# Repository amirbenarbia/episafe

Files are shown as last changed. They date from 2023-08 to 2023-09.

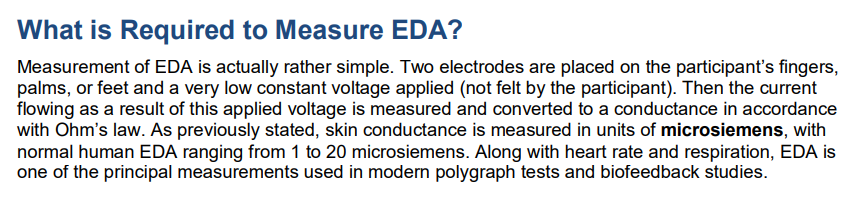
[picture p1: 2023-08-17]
SOLO/EDA/Researches/principeEDA.png

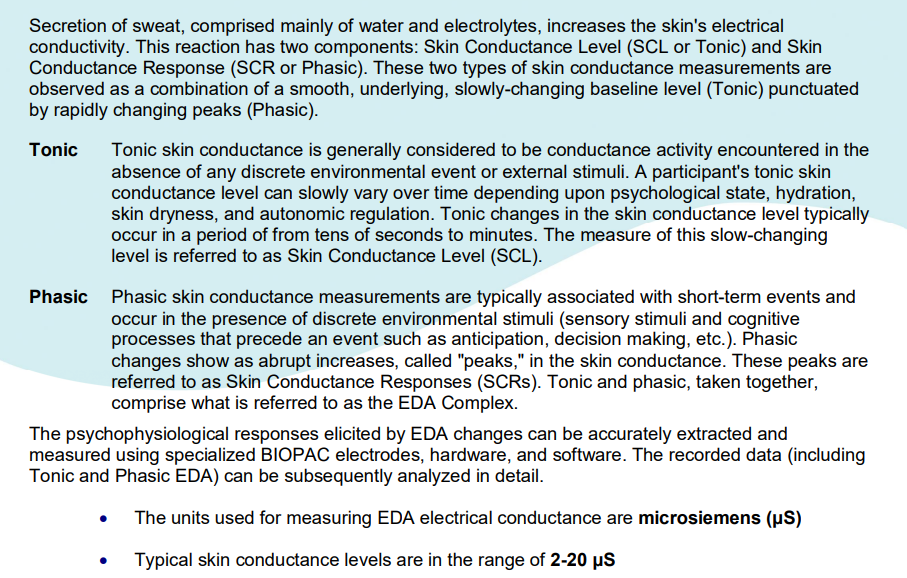
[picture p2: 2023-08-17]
SOLO/EDA/Researches/SCLvsSCR.png

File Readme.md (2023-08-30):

# Episafe Sensor Monitoring System

## Overview

The Episafe Sensor Monitoring System is an embedded IoT system aimed at providing real-time sensor data collection and Bluetooth-based transmission to a host device. Built on the ESP32 microcontroller, the system captures various physiological data points including heart rate, body temperature, acceleration, conductance, and more. With a built-in battery monitoring system, it offers a highly portable and efficient platform for health and safety applications.

## Table of Contents

- [Overview](#overview)
- [Prerequisites](#prerequisites)
- [Installation](#installation)
- [Hardware Setup](#hardware-setup)
- [Usage](#usage)
- [Data Points](#data-points)
- [Error Handling](#error-handling)
- [Contributing](#contributing)
- [License](#license)

## Prerequisites

- ESP32 Development Board
- Arduino IDE (version >= 1.8.10)
- Pulse Sensor
- Adafruit MPU6050 Accelerometer and Gyroscope
- Adafruit MLX90614 Temperature Sensor
- Additional components (LEDs, buttons, etc.)

## Installation

1. **Clone the repository**

   ```
   git clone https://github.com/yourusername/Episafe.git
   ```

2. **Open Arduino IDE**

3. **Install Required Libraries**

   Navigate to `Sketch > Include Library > Manage Libraries...`, then search and install the following libraries:
   - OneButton
   - Adafruit_MLX90614
   - Adafruit_MPU6050
   - BluetoothSerial
   - ArduinoJson

4. **Select Board and Port**

   Choose `ESP32` from `Tools > Board` and select the COM Port the board is connected to.

5. **Compile and Upload**

   Compile the code by clicking the checkmark button, and then upload it to your ESP32 by clicking the right-arrow button.

## Hardware Setup

Follow the hardware schematic [here](link_to_schematic) to connect all the components.

## Usage

The system starts in the "Data Capture" state, where it begins to read the sensor data. The data is stored in an internal buffer until it reaches the specified limit, at which point it moves to the "Data Transmission" state.

### Buttons

- **Button 1**: 
  - Single Click: Manually trigger sensor reading
  - Long Press: Trigger "Crisis" state

- **Button 2**: 
  - Double Click: Report false alarm
  - Long Press: Reset the system

## Data Points

- Heart Rate (BPM)
- Body Temperature (°C)
- Acceleration (m/s^2)
- Conductance (µS)
- Battery Level (%)

## Error Handling

The system has built-in error handling mechanisms to deal with common issues such as Bluetooth disconnection, sensor failures, and more. Errors are indicated by specific LED patterns.

## Contributing

If you wish to contribute, please fork the repository and submit a pull request. For major changes, please open an issue to discuss the proposed changes.

## License

Feel free to clone, modify, and use the code as per your requirements. If you find any issues or have feature requests, please open an issue or submit a pull request.

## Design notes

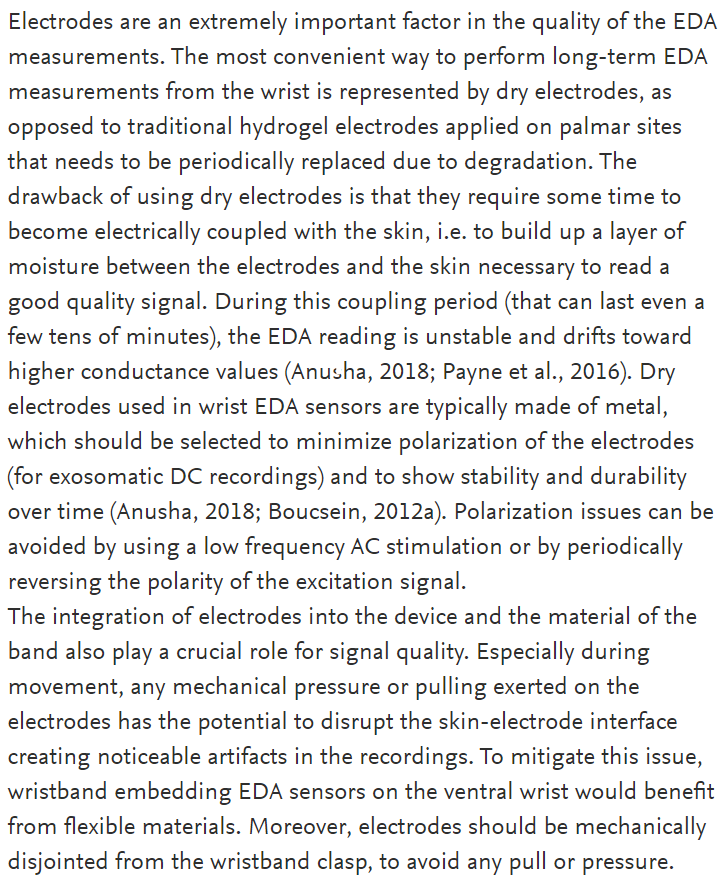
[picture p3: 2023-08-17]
SOLO/EDA/Researches/electrode impact to EDA .png

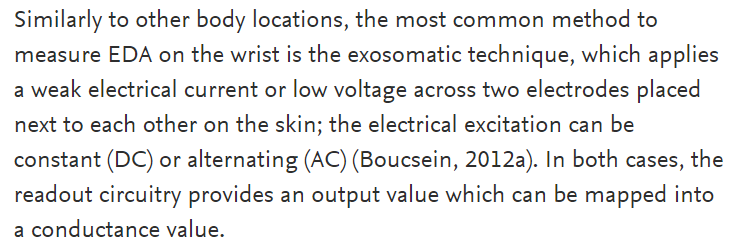
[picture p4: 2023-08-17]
SOLO/EDA/Researches/Wrist method measurments .png

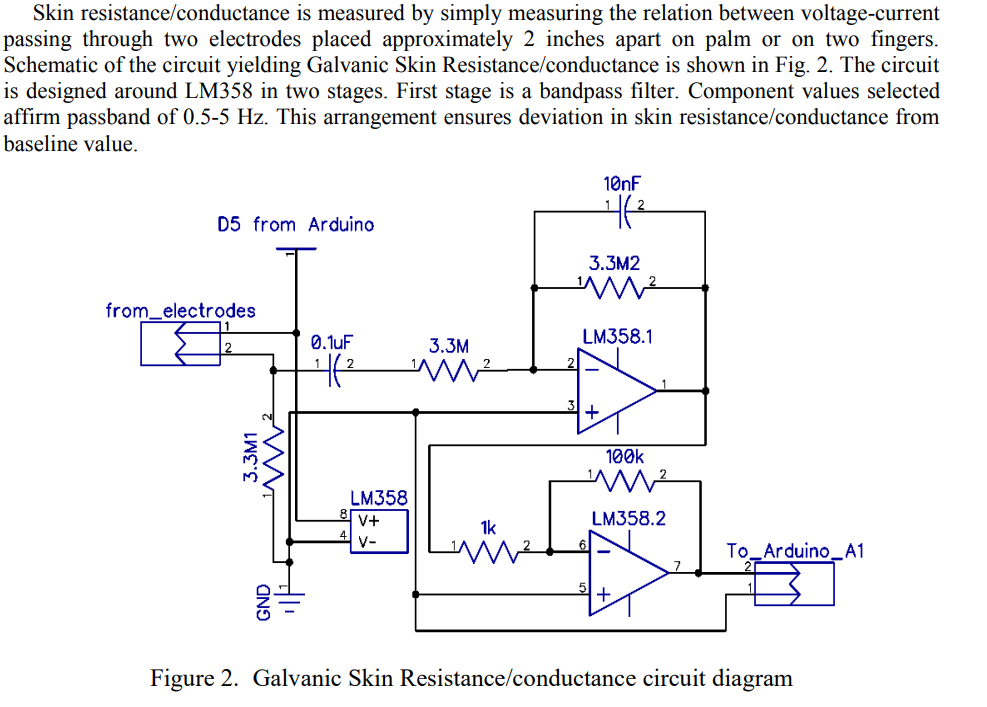
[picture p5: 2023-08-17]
SOLO/EDA/Researches/EDAcircuits2.0.png

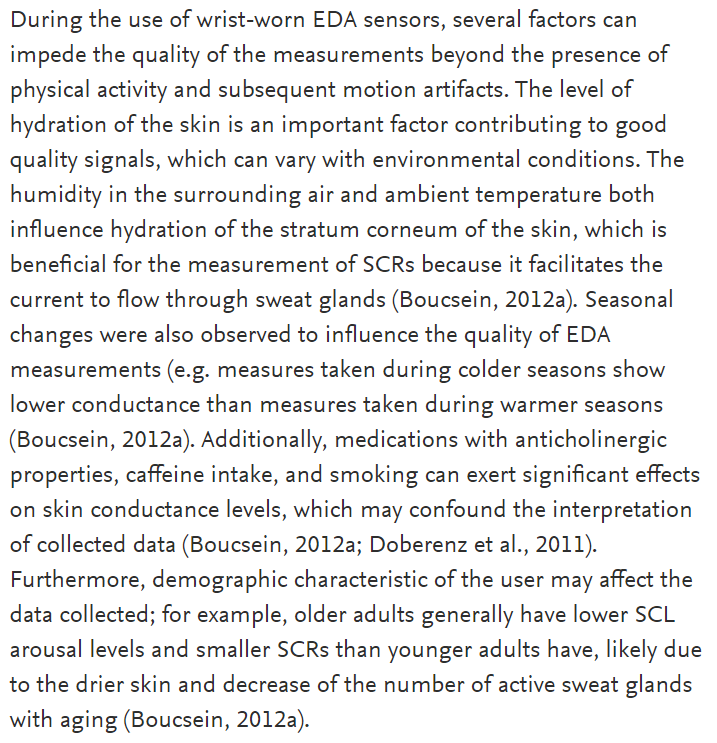
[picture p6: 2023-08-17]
SOLO/EDA/Researches/factors .png

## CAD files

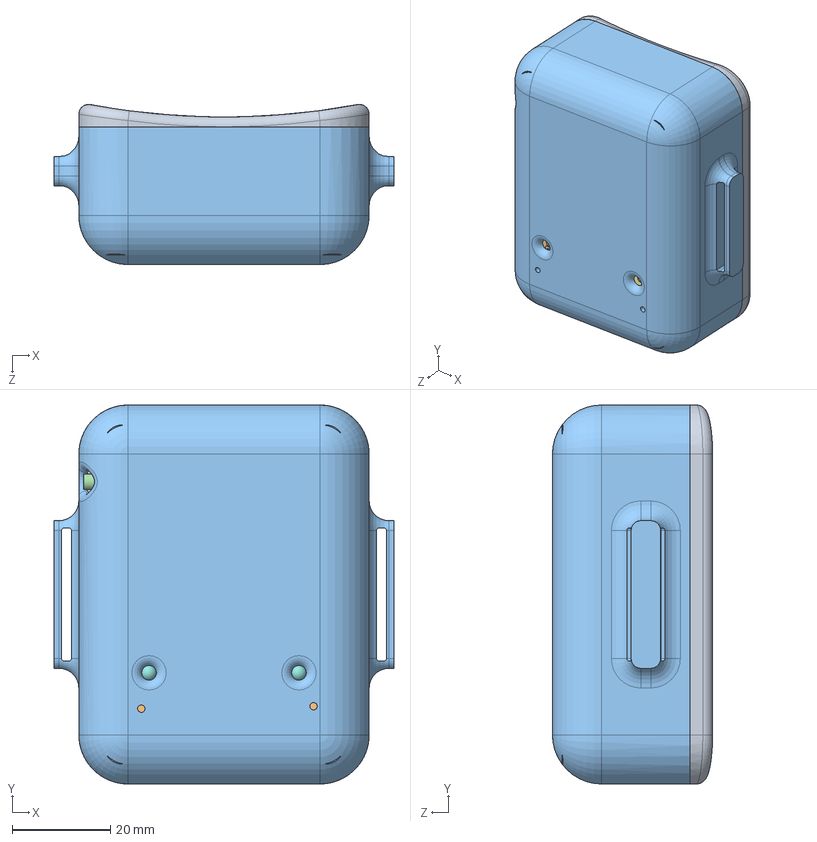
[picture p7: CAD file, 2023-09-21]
EpiSafe_Solidworks/Episafe-assembly-v2.SLDASM
69.0 x 77.0 x 32.6 mm
Episafev1v2(p1)
bt
Episafev2(p2)
SOLID.step x 6
SOLID-0.step x 11
SOLID-1.step x 2
COMPOUND.step
SOLID-2.step x 2
SOLID-3.step
SOLID-4.step x 2
SOLID-5.step
SOLID-6.step
SOLID-7.step
COMPOUND-8.step
COMPOUND-9.step
COMPOUND-10.step
COMPOUND-11.step
Episafe PCB.step

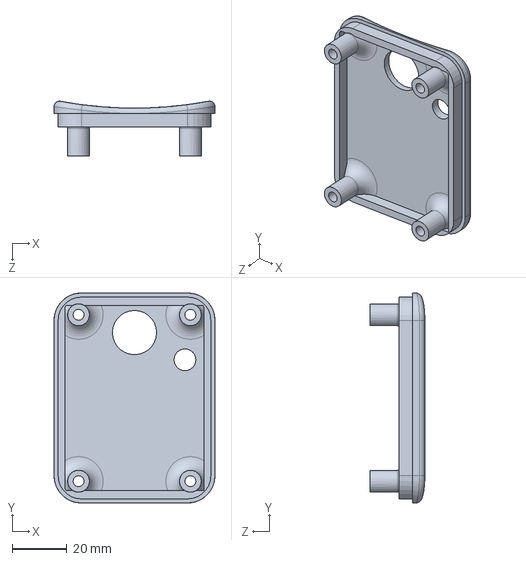
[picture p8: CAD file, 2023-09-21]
EpiSafe_Solidworks/Episafev1v2(p1).SLDPRT
59.0 x 77.0 x 20.1 mm

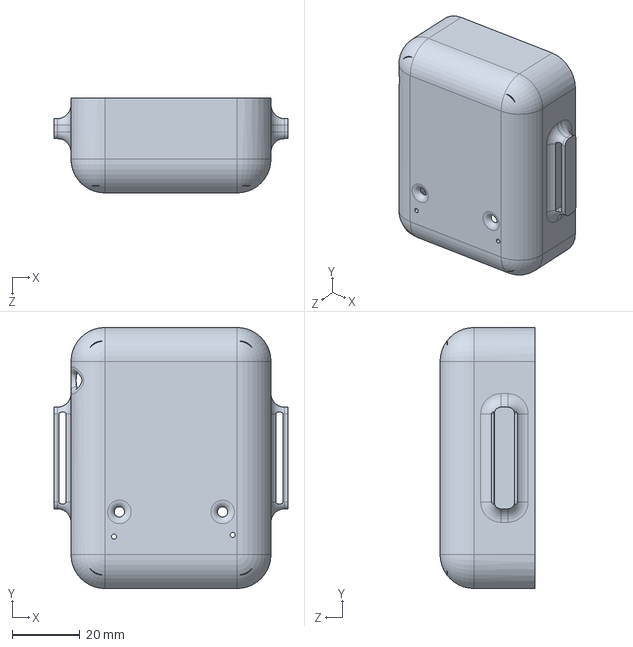
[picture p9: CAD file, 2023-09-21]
EpiSafe_Solidworks/Episafev2(p2).SLDPRT
69.0 x 77.0 x 28.0 mm

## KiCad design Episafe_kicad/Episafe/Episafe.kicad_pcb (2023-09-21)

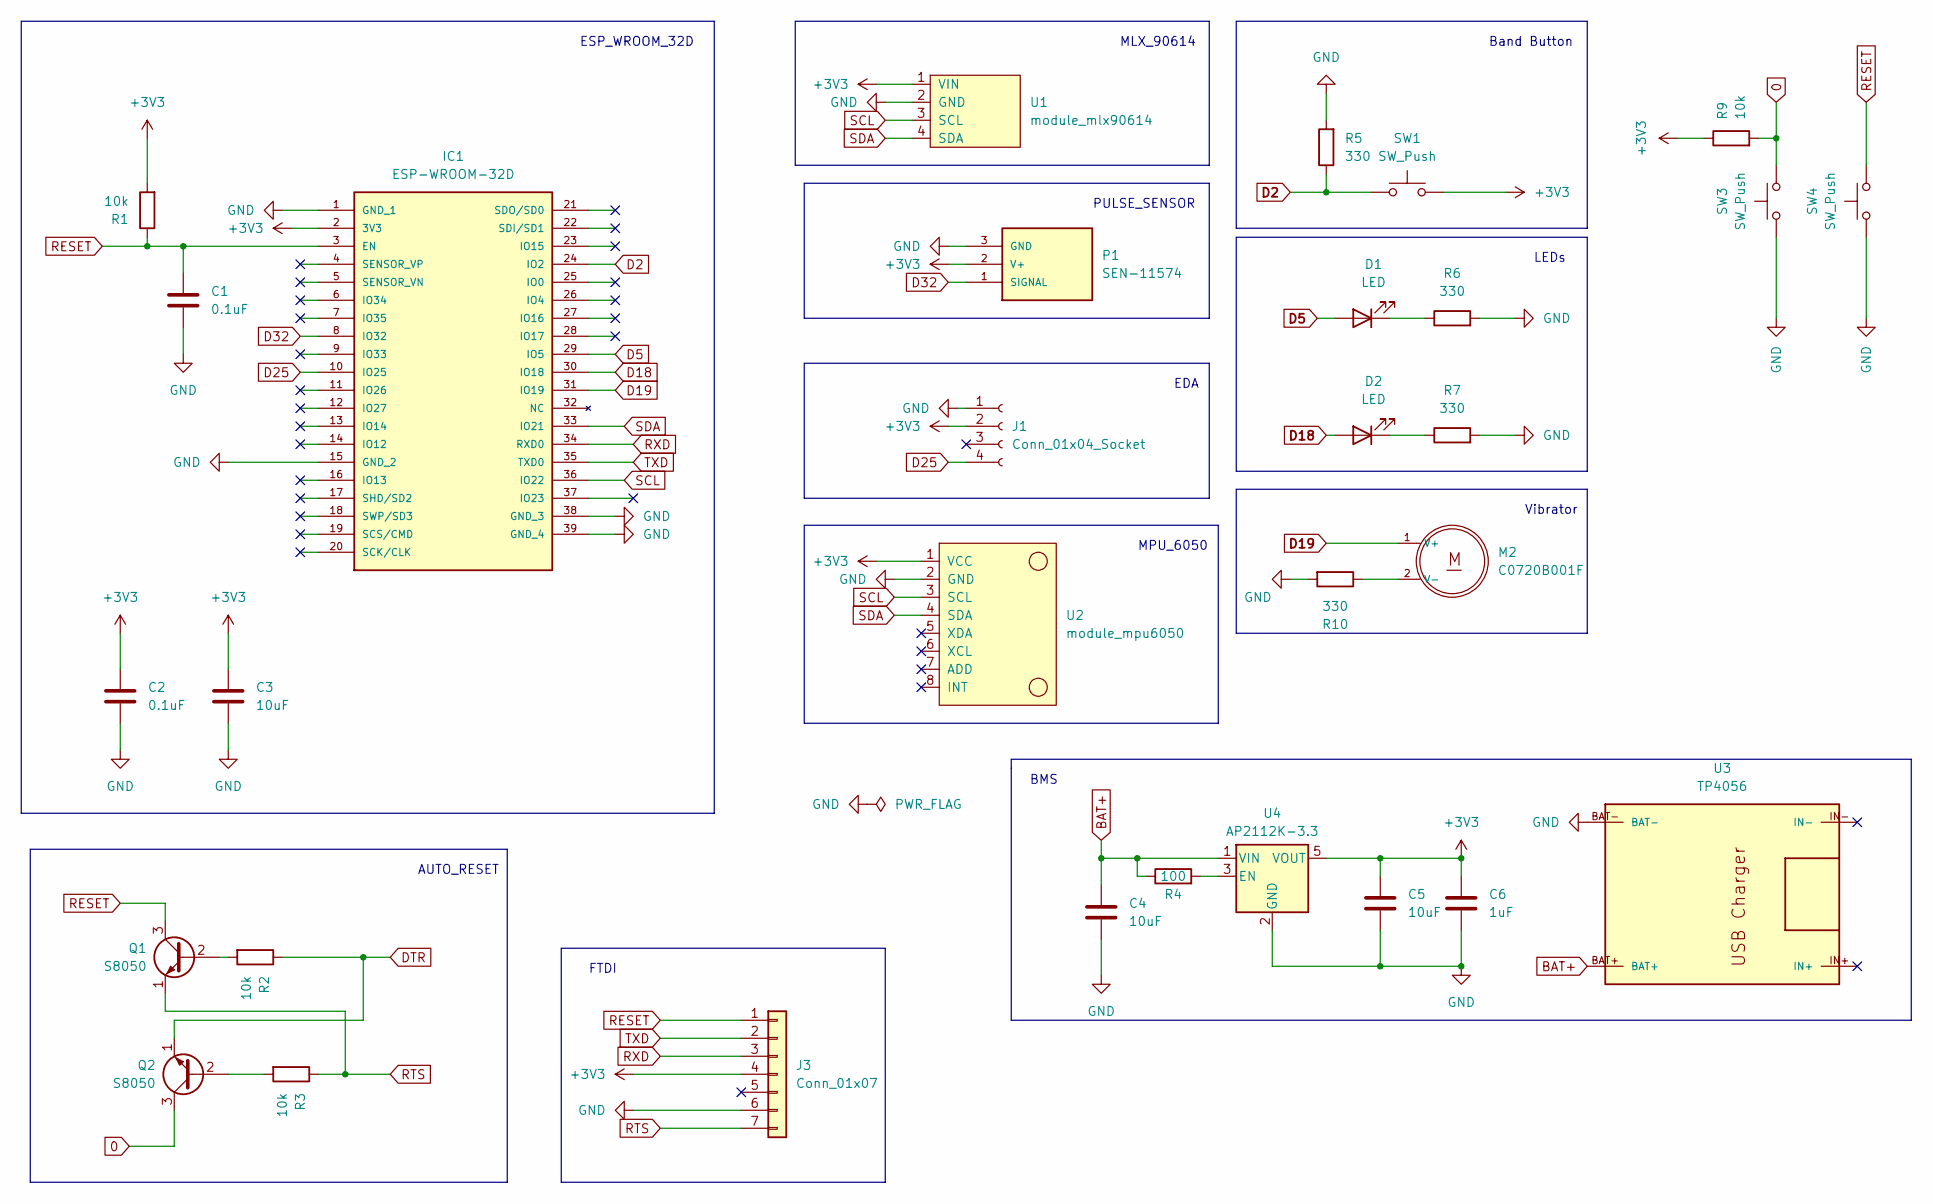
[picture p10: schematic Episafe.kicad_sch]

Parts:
C1, C2: 0.1uF; C_1206_3216Metric_Pad1.33x1.80mm_HandSolder
C3, C4, C5: 10uF; C_1206_3216Metric_Pad1.33x1.80mm_HandSolder
C6: 1uF; C_1206_3216Metric_Pad1.33x1.80mm_HandSolder
D1, D2: LED; LED_D3.0mm
IC1: ESP-WROOM-32D; ESPWROOM32D; MOUSER_PART_NUMBER 356-ESP-WROOM-32D
J1: Conn_01x04_Socket; PinSocket_1x04_P2.54mm_Vertical
J3: Conn_01x07; PinSocket_1x07_P2.54mm_Vertical
M2: C0720B001F; XDCR_C0720B001F
P1: SEN-11574; XDCR_SEN-11574
Q1, Q2: S8050; TO-92_Inline
R1, R2, R3, R9: 10k; R_1206_3216Metric_Pad1.30x1.75mm_HandSolder
R4: 100; R_1206_3216Metric_Pad1.30x1.75mm_HandSolder
R5, R6, R7, R10: 330; R_1206_3216Metric_Pad1.30x1.75mm_HandSolder
SW1, SW3, SW4: SW_Push; SW_DIP_SPSTx01_Slide_6.7x4.1mm_W6.73mm_P2.54mm_LowProfile_J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
U1: module_mlx90614
U2: module_mpu6050
U3: TP4056
U4: AP2112K-3.3; SOT-23-5

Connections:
0: Q2.3 (C), R9.2, SW3.2
+3V3: C2.1, C3.1, C5.1, C6.1, IC1.2 (3V3), J1.2, J3.4, P1.2 (V+), R1.2, R9.1, SW1.2, U1.1 (VIN), U2.1 (VCC), U4.5 (VOUT)
BAT+: C4.1, R4.1, U3.BAT+, U4.1 (VIN)
D2: IC1.24 (IO2), R5.1, SW1.1
D5: D1.2 (A), IC1.29 (IO5)
D18: D2.2 (A), IC1.30 (IO18)
D19: IC1.31 (IO19), M2.1 (V+)
D25: IC1.10 (IO25), J1.4
D32: IC1.8 (IO32), P1.1 (SIGNAL)
DTR: Q2.1 (E), R2.1
GND: C1.2, C2.2, C3.2, C4.2, C5.2, C6.2, IC1.1 (GND_1), IC1.15 (GND_2), IC1.38 (GND_3), IC1.39 (GND_4), J1.1, J3.6, P1.3 (GND), R5.2, R6.2, R7.2, R10.2, SW3.1, SW4.1, U1.2 (GND), U2.2 (GND), U3.BAT-, U4.2 (GND)
unnamed: D1.1 (K), R6.1
unnamed: D2.1 (K), R7.1
unnamed: M2.2 (V-), R10.1
unnamed: Q1.2 (B), R2.2
unnamed: Q2.2 (B), R3.2
unnamed: R4.2, U4.3 (EN)
RESET: C1.1, IC1.3 (EN), J3.1, Q1.3 (C), R1.1, SW4.2
RTS: J3.7, Q1.1 (E), R3.1
RXD: IC1.34 (RXD0), J3.3
SCL: IC1.36 (IO22), U1.3 (SCL), U2.3 (SCL)
SDA: IC1.33 (IO21), U1.4 (SDA), U2.4 (SDA)
TXD: IC1.35 (TXD0), J3.2

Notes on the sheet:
EDA
PULSE_SENSOR
MLX_90614
FTDI
MPU_6050
Vibrator
AUTO_RESET
ESP_WROOM_32D
BMS
LEDs
Band Button

Board: 2 copper layers, 31 parts (1 on the bottom side), 23 nets, no tracks yet.

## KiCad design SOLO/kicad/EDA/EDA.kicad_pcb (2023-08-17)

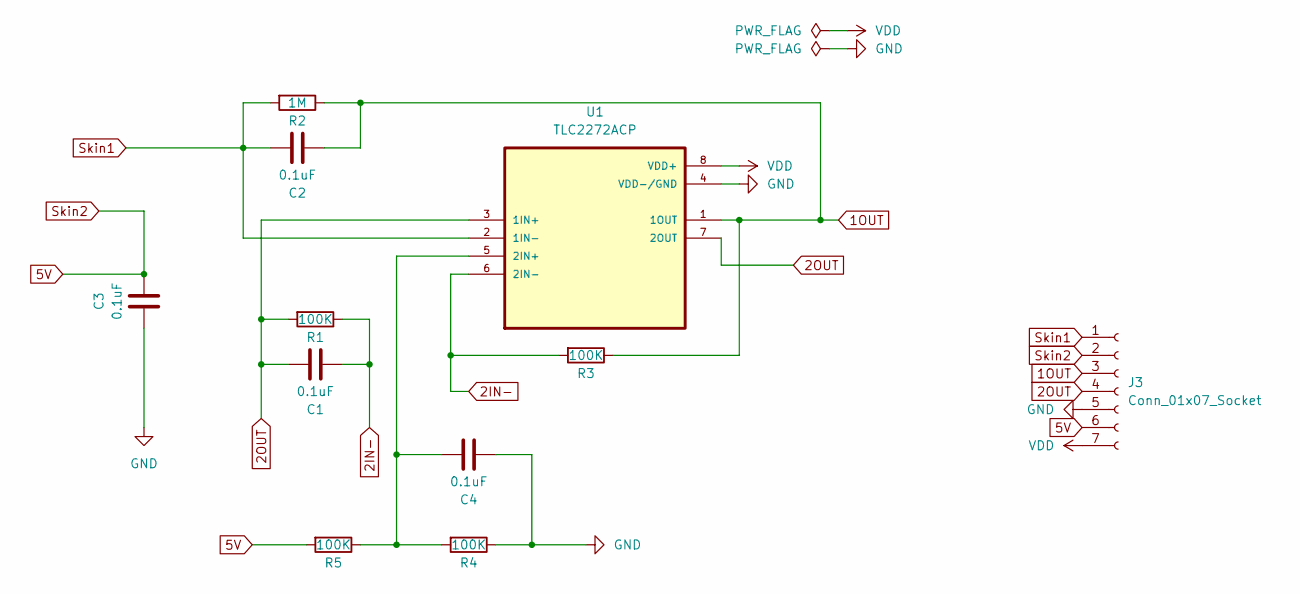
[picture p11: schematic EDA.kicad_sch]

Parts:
C1, C2, C3, C4: 0.1uF; C_Disc_D3.0mm_W1.6mm_P2.50mm
J3: Conn_01x07_Socket; JST_XH_B7B-XH-A_1x07_P2.50mm_Vertical
R1, R3, R4, R5: 100K; R_Axial_DIN0207_L6.3mm_D2.5mm_P10.16mm_Horizontal
R2: 1M; R_Axial_DIN0207_L6.3mm_D2.5mm_P10.16mm_Horizontal
U1: TLC2272ACP; DIP794W45P254L959H508Q8

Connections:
1OUT: C2.1, J3.3, R2.1, R3.1, U1.1 (1OUT)
2IN-: C1.1, R1.1, R3.2, U1.6 (2IN-)
2OUT: C1.2, J3.4, R1.2, U1.3 (1IN+), U1.7 (2OUT)
5V: C3.2, J3.2, J3.6, R5.2; also elsewhere on the board
GND: C3.1, C4.1, J3.5, R4.1, U1.4 (VDD-/GND)
unnamed: C4.2, R4.2, R5.1, U1.5 (2IN+)
Skin1: C2.2, J3.1, R2.2, U1.2 (1IN-)
VDD: J3.7, U1.8 (VDD+)

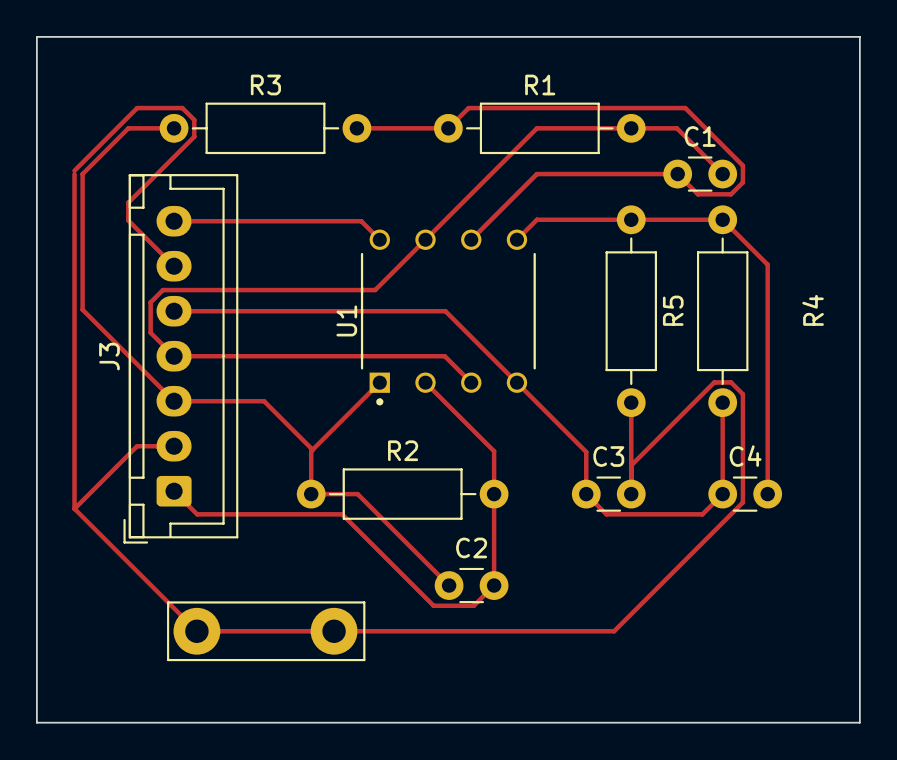
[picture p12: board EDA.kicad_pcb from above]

Board: 2 copper layers, 45.7 x 38.1 mm, 12 parts (0 on the bottom side), 8 nets.

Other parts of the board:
JP1: Jumper_2_Open; TestPoint_Bridge_Pitch7.62mm_Drill1.3mm

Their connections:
5V: JP1.1 (A); also elsewhere on the board

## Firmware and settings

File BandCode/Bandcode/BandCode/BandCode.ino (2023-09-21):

#include <OneButton.h>
#include <Wire.h>
#include <Adafruit_MLX90614.h>
#include <BluetoothSerial.h>
#include <Adafruit_MPU6050.h>
#include <Adafruit_Sensor.h>
#include <ArduinoJson.h>

extern "C" {
#include "esp_bt_device.h"
}

#define vib 19
#define pb1 2
//#define pb2 4
#define PulseSensorPurplePin 32
#define EDA_pin 25
#define LED_ERROR_PIN 5
#define LED_Sent 5
#define LED_collect 18
#define EDA_TH_PER_EPOCH 5
#define MAX_READ 1024
#define Threshold 2000
#define DURATION_COLLECT 250
#define DURATION_SENDING 1500
#define RECORDING_DURATION 20 * 1000
#define DATA_INTERVAL 250
#define MAX_DATA_POINTS RECORDING_DURATION / DATA_INTERVAL

int enableDebugOutput = 0;
TaskHandle_t BluetoothTaskHandle = NULL;
TaskHandle_t ButtonTaskHandle = NULL;

OneButton b1 = OneButton(
  pb1,    // Input pin for the button
  false,  // Button is active high
  false   // Disable internal pull-up resistor
);
/*OneButton b2 = OneButton(
  pb2,    // Input pin for the button
  false,  // Button is active high
  false   // Disable internal pull-up resistor
);*/
enum ErrorType { BT_DISCONNECTED,
                 BT_DISCONNECTED_WHILE_SENDING,
                 SENSOR_INIT_FAIL,
                 EDA_NEG };
struct SensorData {
  int pulseSensorValue;
  float objectTempC;
  float conductance;
  float accelerationX;
  float accelerationY;
  float accelerationZ;
  float temperature;
  float timeStamp;
  float batteryLevel;
};



void showError(ErrorType error);
float read_eda(int pin);
String Query(SensorData dt);
void readSensors(SensorData& data);
void sensorTask(void* parameter);
void bluetoothTask(void* parameter);
void blinkLED(int ledPin, int blinkDuration, int);
float readBatteryLevel(int pin);
float roundToOneDecimal(float num);
void  readHeartRateSensor(SensorData& data); 
void readTemperatureSensor(SensorData& data); 
void readAccelerometer(SensorData& data); 
void readEDA(SensorData& data); 
  
BluetoothSerial SerialBT;
Adafruit_MPU6050 mpu;
Adafruit_MLX90614 mlx = Adafruit_MLX90614();
int Signal, beatsPerMinute;
unsigned long lastBeatTime = 0, currentBeatTime, startTime;
int dataCount = 0;

SensorData dataBuffer[MAX_DATA_POINTS];

QueueHandle_t dataQueue;
String dataString = "";
int BATTERY_PIN = 3;
uint8_t mac[6];

void setup() {
  Serial.begin(115200);
  pinMode(EDA_pin, INPUT);
  pinMode(vib, OUTPUT);
  setupButtons(); //push buttons
  mlx.begin();
  mpu.begin();
  SerialBT.begin("Episafe");
  dataQueue = xQueueCreate(5, sizeof(SensorData));
  esp_read_mac(mac, ESP_MAC_BT);
  xTaskCreatePinnedToCore(sensorTask, "SensorTask", 30000, NULL, 1, NULL, 0);
  xTaskCreatePinnedToCore(buttonTask,"ButtonTask",30000,NULL,2,&ButtonTaskHandle,1);
}
void loop() {
  b1.tick();
  vTaskDelay(pdMS_TO_TICKS(500));
}

void showError(ErrorType error) {
  switch (error) {
    case BT_DISCONNECTED:
        Serial.println("Bluetooth Disconnected!");
      blinkLED(LED_ERROR_PIN, 300, 3);
      break;
    case SENSOR_INIT_FAIL:
        Serial.println("Sensor Initialization Failed!");
      blinkLED(LED_ERROR_PIN, 300, 3);
      break;
    case EDA_NEG:
        Serial.println("EDA-conductance negative");
      blinkLED(LED_ERROR_PIN, 150, 2);
      break;
    case BT_DISCONNECTED_WHILE_SENDING:
        Serial.println("FAILED TO SEND..");
      blinkLED(LED_ERROR_PIN, 150, 4);
      break;
  }
}
float read_eda(int pin) {
  int sensorValue = 0;
  int gsr_average = 0;
  int human_resistance = 0;
  int EDA_th_per_epch = 5;

  long sum = 0;
  for (int i = 0; i < EDA_th_per_epch; i++) {
    sensorValue = analogRead(pin);
    sum += sensorValue;
  }
  gsr_average = sum / EDA_th_per_epch;
  human_resistance = ((4096 + 2 * gsr_average) * 10000) / (2048 - gsr_average);

  return ((1.0 / human_resistance) * 1000000);
}
String Query(SensorData dt) {
  String result;

  result += "EPISAFE/";
  result += String(mac[0], HEX) + ":" + String(mac[1], HEX) + ":" + String(mac[2], HEX) +String(mac[3], HEX) + ":" + String(mac[4], HEX) + ":" + String(mac[5], HEX) + ",";
  result += String(roundToOneDecimal(dt.timeStamp)) + ",";
  result += String(roundToOneDecimal(dt.pulseSensorValue)) + ",";
  result += String(roundToOneDecimal(dt.objectTempC)) + ",";
  result += String(roundToOneDecimal(dt.accelerationX)) + ",";
  result += String(roundToOneDecimal(dt.accelerationY)) + ",";
  result += String(roundToOneDecimal(dt.accelerationZ)) + ",";
  result += String(roundToOneDecimal(dt.temperature)) + ",";
  result += String(roundToOneDecimal(dt.conductance)) + ",";
  result += String(roundToOneDecimal(dt.batteryLevel));

  result += "#";

  return result;
}

void readSensors(SensorData& data) {
  //HR
  readHeartRateSensor(data); 

  //TMPC
  readTemperatureSensor(data); 

  //ACC
  readAccelerometer(data); 

  //EDA
  readEDA(data); 

  //battery
  read_batt_lvl(data);   

  //---------
  if (dataCount < MAX_DATA_POINTS) {
    dataBuffer[dataCount] = data;
    dataCount++;
  }
  data.timeStamp = (float)(millis() - startTime) ; 


  if (!enableDebugOutput)
    Serial.print(".-");

}

void sensorTask(void* parameter) {
  while (1) {
    SensorData data;
    if (enableDebugOutput)
      Serial.printf("--------------capture Data Task running on core %d----------------\n", xPortGetCoreID());
    readSensors(data);
    blinkLED(LED_collect, DURATION_COLLECT, 1);
    if (millis() - startTime >= RECORDING_DURATION) {
      if (BluetoothTaskHandle == NULL) {
        xTaskCreatePinnedToCore(bluetoothTask,"BluetoothTask",2000,NULL,1,&BluetoothTaskHandle,1);
        startTime = millis();
      }
      xQueueSend(dataQueue, &data, portMAX_DELAY);
      vTaskDelay(pdMS_TO_TICKS(100));
    }
  }
}

void bluetoothTask(void* parameter) {
  SensorData data;
  bool allDataSent = false;  // Flag to track if all data has been sent

  while (1) {
    // Reset the flag when entering the loop
    allDataSent = false;

    if (xQueueReceive(dataQueue, &data, portMAX_DELAY)) {
      dataString = "";
      if (enableDebugOutput)
        Serial.printf("--------------Send Data Task running on core %d----------------\n", xPortGetCoreID());

      if (check_bl_cnx()) {
        SerialBT.println(dataCount); 
        for (int i = 0; i < dataCount; i++) {

          String load = Query(dataBuffer[i]);
          Serial.println(load);
          SerialBT.println(load);
          delay(10);

          // Check if this is the last data point to be sent
          if (i == dataCount - 1) {
            allDataSent = true;
          }
        }
        if (allDataSent) { // Exit task only if all data is sent
          blinkLED(LED_collect, DURATION_SENDING*2, 2);
          blinkLED(LED_Sent, DURATION_SENDING*2, 2);
          dataCount = 0;
          xQueueReset(dataQueue);
          break; // Exiting the while loop

        }
      }
    }
  }

  BluetoothTaskHandle = NULL;
  vTaskDelete(NULL);
}

float readBatteryLevel(int pin) {
  pinMode(pin, INPUT);
  int raw = analogRead(pin);
  // Convert the raw reading into voltage, assuming 3.3V reference
  float voltage = (float)raw / 4095.0 * 3.3;

  // Convert voltage to percentage, assuming 3.3V is 100% and 0V is 0%
  float percentage = (voltage / 3.3) * 100;
  percentage = 33;
  return percentage;
}
void blinkLED(int ledPin, int blinkDuration = 500, int time = 2) {
  pinMode(ledPin, OUTPUT);
  for (int i = 0; i < time; i++) {
    digitalWrite(ledPin, HIGH);
    delay(blinkDuration / 2);

    digitalWrite(ledPin, LOW);
    delay(blinkDuration / 2);
  }
}
float roundToOneDecimal(float num) {
  return round(num * 10.0) / 10.0;
}
/*void trig_sensor() {
  Serial.println("trig_senor");
}*/
void crise() {
  Serial.println("crise");
  vibr(200,3); 
}
/*void reset() {
  Serial.println("reset");
  ESP.restart();
}*/
void debug() {
  Serial.println("debug");
  enableDebugOutput = !enableDebugOutput;
}
void false_alarm() {
  Serial.println("False_alarme");
  vibr(150,1); 
}
void setupButtons() {

  pinMode(pb1, OUTPUT);

  b1.attachClick(debug);
  b1.attachDuringLongPress(crise);
  b1.attachDoubleClick(false_alarm);
  b1.setLongPressIntervalMs(3000);
  b1.setClickMs(300);
}
void buttonTask(void* parameter) {
  while (1) {
    b1.tick();
    vTaskDelay(pdMS_TO_TICKS(20));
  }
}
void vibr(int dur, int x) {

  for (int i = 0; i < x; i++) {
    digitalWrite(vib, 1);
    delay(dur);
    digitalWrite(vib, 0);
  }
}
int check_bl_cnx() {
  if (SerialBT.hasClient())
    return 1;
  else
    showError(BT_DISCONNECTED);
  delay(100);
  return 0;
}
void check_sensors() {
  if (!mpu.begin()) showError(SENSOR_INIT_FAIL);
  if (!mlx.begin()) showError(SENSOR_INIT_FAIL);
}

void readHeartRateSensor(SensorData& data) {
  data.pulseSensorValue = analogRead(PulseSensorPurplePin);
  Signal = data.pulseSensorValue;
  currentBeatTime = millis();

  if (Signal > Threshold && (currentBeatTime - lastBeatTime) > 200) {
    int beatInterval = currentBeatTime - lastBeatTime;
    beatsPerMinute = 60000 / beatInterval;
    lastBeatTime = currentBeatTime;
    data.pulseSensorValue = beatsPerMinute ; 
    if (enableDebugOutput) {
      Serial.print("Heart Rate: ");
      Serial.print(beatsPerMinute);
      Serial.println(" BPM");
      delay(50);
    }
  }
}

void readTemperatureSensor(SensorData& data) {
  data.objectTempC = mlx.readObjectTempC();
  if (enableDebugOutput) {
    Serial.print("Temperature corp = ");
    Serial.print(data.objectTempC);
    Serial.println("°C");
  }
}

void readAccelerometer(SensorData& data) {
  sensors_event_t a, g, temp;
  mpu.getEvent(&a, &g, &temp);

  data.accelerationX = a.acceleration.x;
  data.accelerationY = a.acceleration.y;
  data.accelerationZ = a.acceleration.z;
  data.temperature = temp.temperature;

  if (enableDebugOutput) {
    Serial.print("Acceleration X: ");
    Serial.print(a.acceleration.x);
    Serial.print(", Y: ");
    Serial.print(a.acceleration.y);
    Serial.print(", Z: ");
    Serial.print(a.acceleration.z);
    Serial.println(" m/s^2");

    Serial.print("Temperature: ");
    Serial.print(temp.temperature);
    Serial.println(" degC");
  }
}

void readEDA(SensorData& data) {
  int x = read_eda(EDA_pin);
  if (x >= 0) {
    data.conductance = x;
    if (enableDebugOutput) {
      Serial.print("eda value=");
      Serial.println(x);
    }
  } else {
    showError(EDA_NEG);
  }
}

void read_batt_lvl(SensorData& data){
  data.batteryLevel = readBatteryLevel(BATTERY_PIN);
  if (enableDebugOutput) {
    Serial.print("Battery Level: ");
    Serial.print(data.batteryLevel);
    Serial.println("%");
  }
}

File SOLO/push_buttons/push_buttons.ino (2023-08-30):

#include <OneButton.h>
#define pb1 2
#define pb2 4

OneButton b1 = OneButton(
  pb1,    // Input pin for the button
  false,  // Button is active high
  false   // Disable internal pull-up resistor
);

OneButton b2 = OneButton(
  pb2,    // Input pin for the button
  false,  // Button is active high
  false   // Disable internal pull-up resistor
);

void setup() {
  Serial.begin(115200); 
  setupButtons()  ; 


}
void loop() {
  // put your main code here, to run repeatedly:
  b1.tick();
  b2.tick();
}

void trig_sensor() {
  Serial.println("trig_senor");
  
}
void crise() {
  Serial.println("crise");
  
}
void reset() {
  Serial.println("reset");
  
}
void false_alarm() {
  Serial.println("False_alarme");
  
}

void setupButtons(){

  pinMode(pb1, OUTPUT);
  pinMode(pb2, OUTPUT);

  b1.attachClick(trig_sensor);
  b1.attachDuringLongPress(crise);

  b2.attachDuringLongPress(reset);
  b2.attachDoubleClick(false_alarm);

  b1.setLongPressIntervalMs(1000);
  b2.setLongPressIntervalMs(2000);

  b2.setClickMs(320); 
}

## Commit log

2023-08-22 update dir
    [EDA.kicad_pcb, EDA.kicad_sch]
2023-08-28 battery level
2023-08-28 json battery mac
2023-08-29 add buttons and debugcontrol
2023-08-31 task management and reset implementation
    [BandCode.ino]
2023-09-21 Solid kicad V2
    [Episafe-assembly-v2.SLDASM, Episafe.kicad_pcb, Episafe.kicad_sch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]
